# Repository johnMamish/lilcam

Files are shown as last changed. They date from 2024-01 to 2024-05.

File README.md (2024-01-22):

This is a USB camera which uses the ultra-low-power Himax HM01B0 and HM0360 sensors. It's intended to act as an evaluation platform for these sensors; commercially available evaluation platforms don't allow for the use of custom optics.

Please contact me if you're interested in buying one, we might be able to set something up.

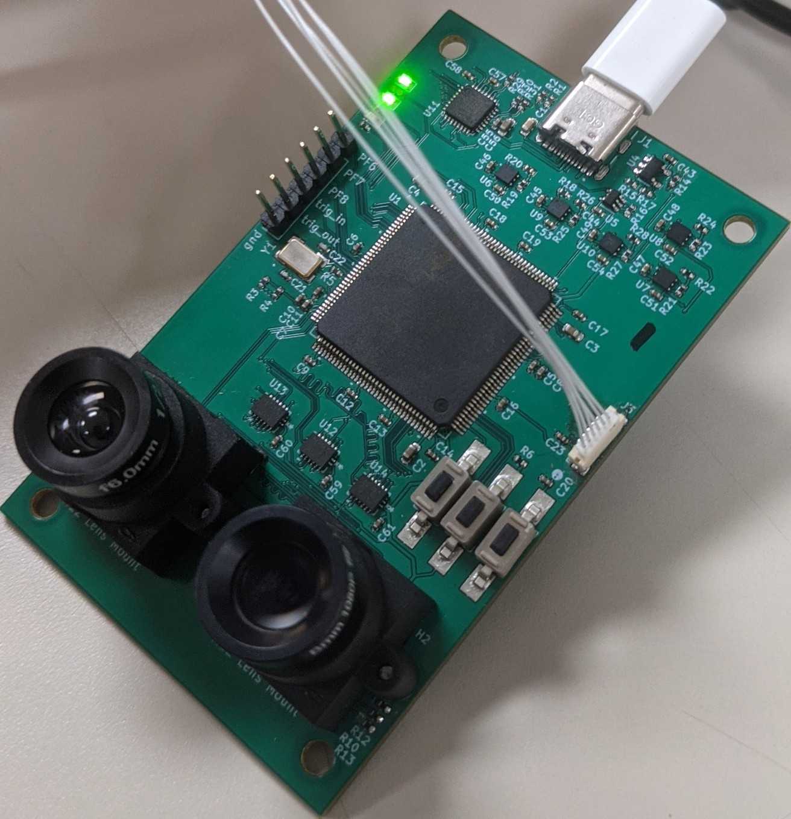
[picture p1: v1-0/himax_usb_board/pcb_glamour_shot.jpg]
photo of PCB


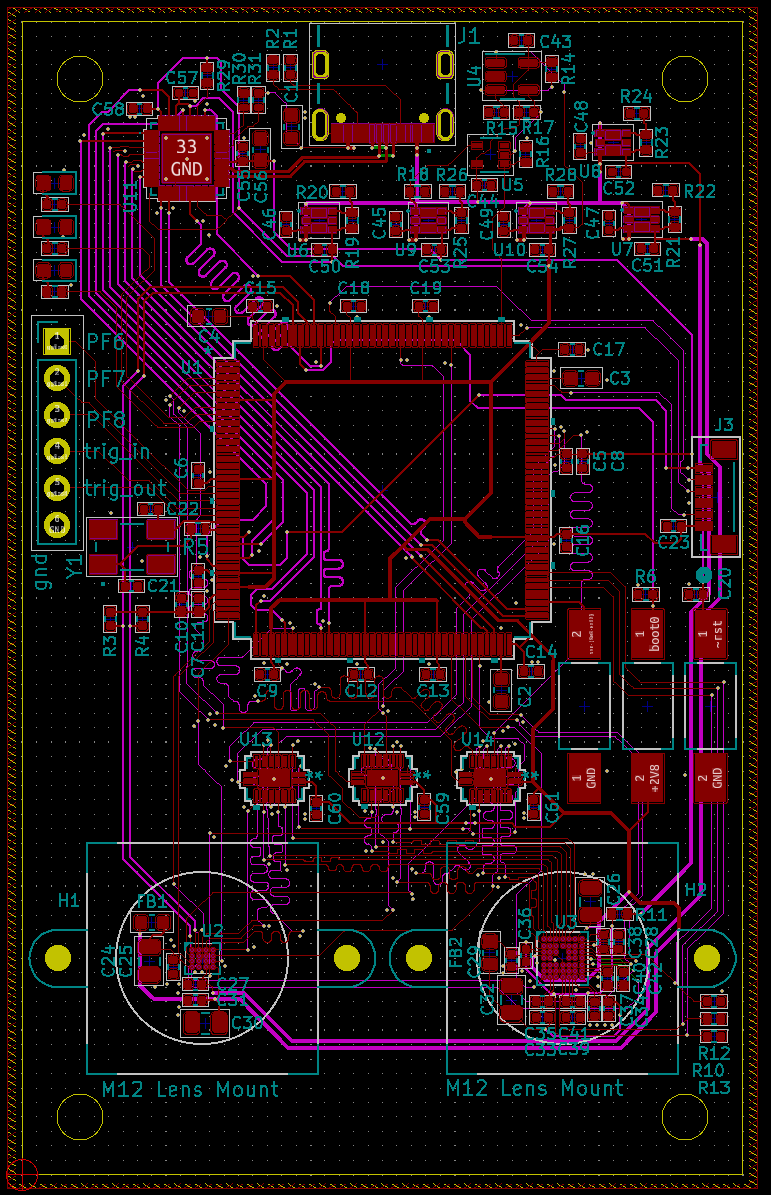
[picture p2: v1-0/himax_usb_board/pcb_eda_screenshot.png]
screenshot of EDA design


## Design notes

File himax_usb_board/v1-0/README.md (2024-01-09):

Power rails needed:
 - 3v3
    - STM32 VDDUSB   Note - must be sequenced properly.
                     Enough to have an 'enable' pin from the microcontroller plus an
 - 2v8
    - STM32 VDD      Note that I can expect it to consume ~100mA
    - HM01B0 IOVDD
    - HM01B0 AVDD
    - HM0360 IOVDD
    - HM0360 AVDD
 - 1v5
    - HM01B0 DVDD
 - 1v2
    - HM0360 DVDD

#### Schematic checklist
 - [x] STM32
     - [x] inter-module sync signal
     - [x] a few gpio for controlling external stuff
     - [x] programming connector
     - [x] a couple LEDs and buttons
     - [x] BOOT0 / reset button
 - [x] USB
     - [x] tvs diodes  (USB3300 has integrated TVS diodes)
     - [x] ULPI transciever
           USB3320
         - [x] refclk
               going to wait to start layout to decide which pin will work the best for this.
               STM32 can't generate clock on ULPI bus.
         - [x] gpio vol] i2c selection pins
 - [x] image sensor bus switch
     - [x] muxes
     - [x] camera select signal
 - [x] hm0360
     - [x] i2c selection pins
     - [x] mclk; should we provide an external clock?
           yes.
     - [x] xsleep, xshutdown, etc
     - [x] strobe
     - [x] int
 - [x] hm01b0
     - [x] mclk; should we provide an external clock?
     - [x] strobe
     - [x] int
 - [x] i2c pullups
 - [x] Crystal capacitor selection
 - [ ] check ground vias

#### PCB checklist
 - [x] lens mounting holes
 - [ ] add current sensing?

Bringup todos
 - [ ] Verify power down sequencing

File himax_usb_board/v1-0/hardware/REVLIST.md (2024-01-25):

#### Electrical
 - [ ] voltage divider going into op-amp for power supply sequencing has incorrect
       value on top. Should be < ~7.5kOhm
 - [ ] ULPI transciever might benefit from a reset line connected to MCU. This
 - [ ] Silkscreen around buttons
 - [ ] No boot0 button, but extra user button (?)
 - [ ] Mounting holes for lens mount too small
 - [ ] Two of the broken out pins should be a DFU-capable
 - [-] Sometimes camera doesnt start on initial power-on, but needs a reset cycle. Why?
       This was because the hm01b0 pixclk being configured as gated. The STM32 has an undocumented requirement that the DCMI pixclk be continuous
 - [ ] Change clock refsel bits on PHY
 - [ ] Add some sort of 'board id' resistors so that firmware can tell which board its on

#### Electrical tentative
 - [ ] Also break out FS usb port?
 - [ ] Add current monitoring for camera power rails
 - [ ] Swap MCU to chip with more flash?
 - [ ] External RAM (buffer images, fun)
 - [ ] External Flash (?)

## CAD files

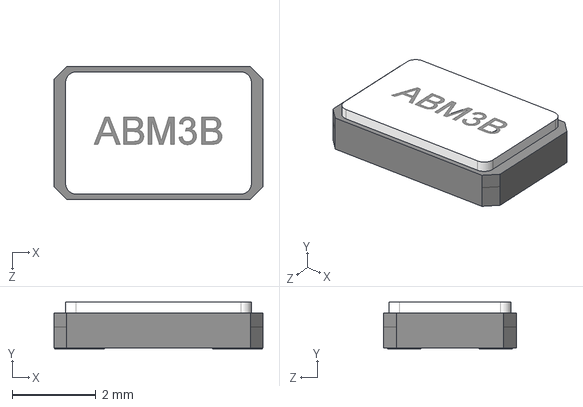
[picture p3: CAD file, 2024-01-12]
himax_usb_board/v1-0/hardware/ABM3B_12_000MHZ_B2_T/ABM3B-12.000MHZ-B2-T.step
5.00 x 1.11 x 3.18 mm

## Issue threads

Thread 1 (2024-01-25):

Change to tinyusb library + isochronous usb

johnMamish, 2024-01-25:
Currently using STM32CubeMX driver. It handles high bandwidth stuff poorly. We can do 320x240 up to ~30fps, but that's not remotely sufficient.

Should switch to a combo of tinyusb + my own code. Furthermore, we ought to change to an isochronous endpoint so we can do video properly.

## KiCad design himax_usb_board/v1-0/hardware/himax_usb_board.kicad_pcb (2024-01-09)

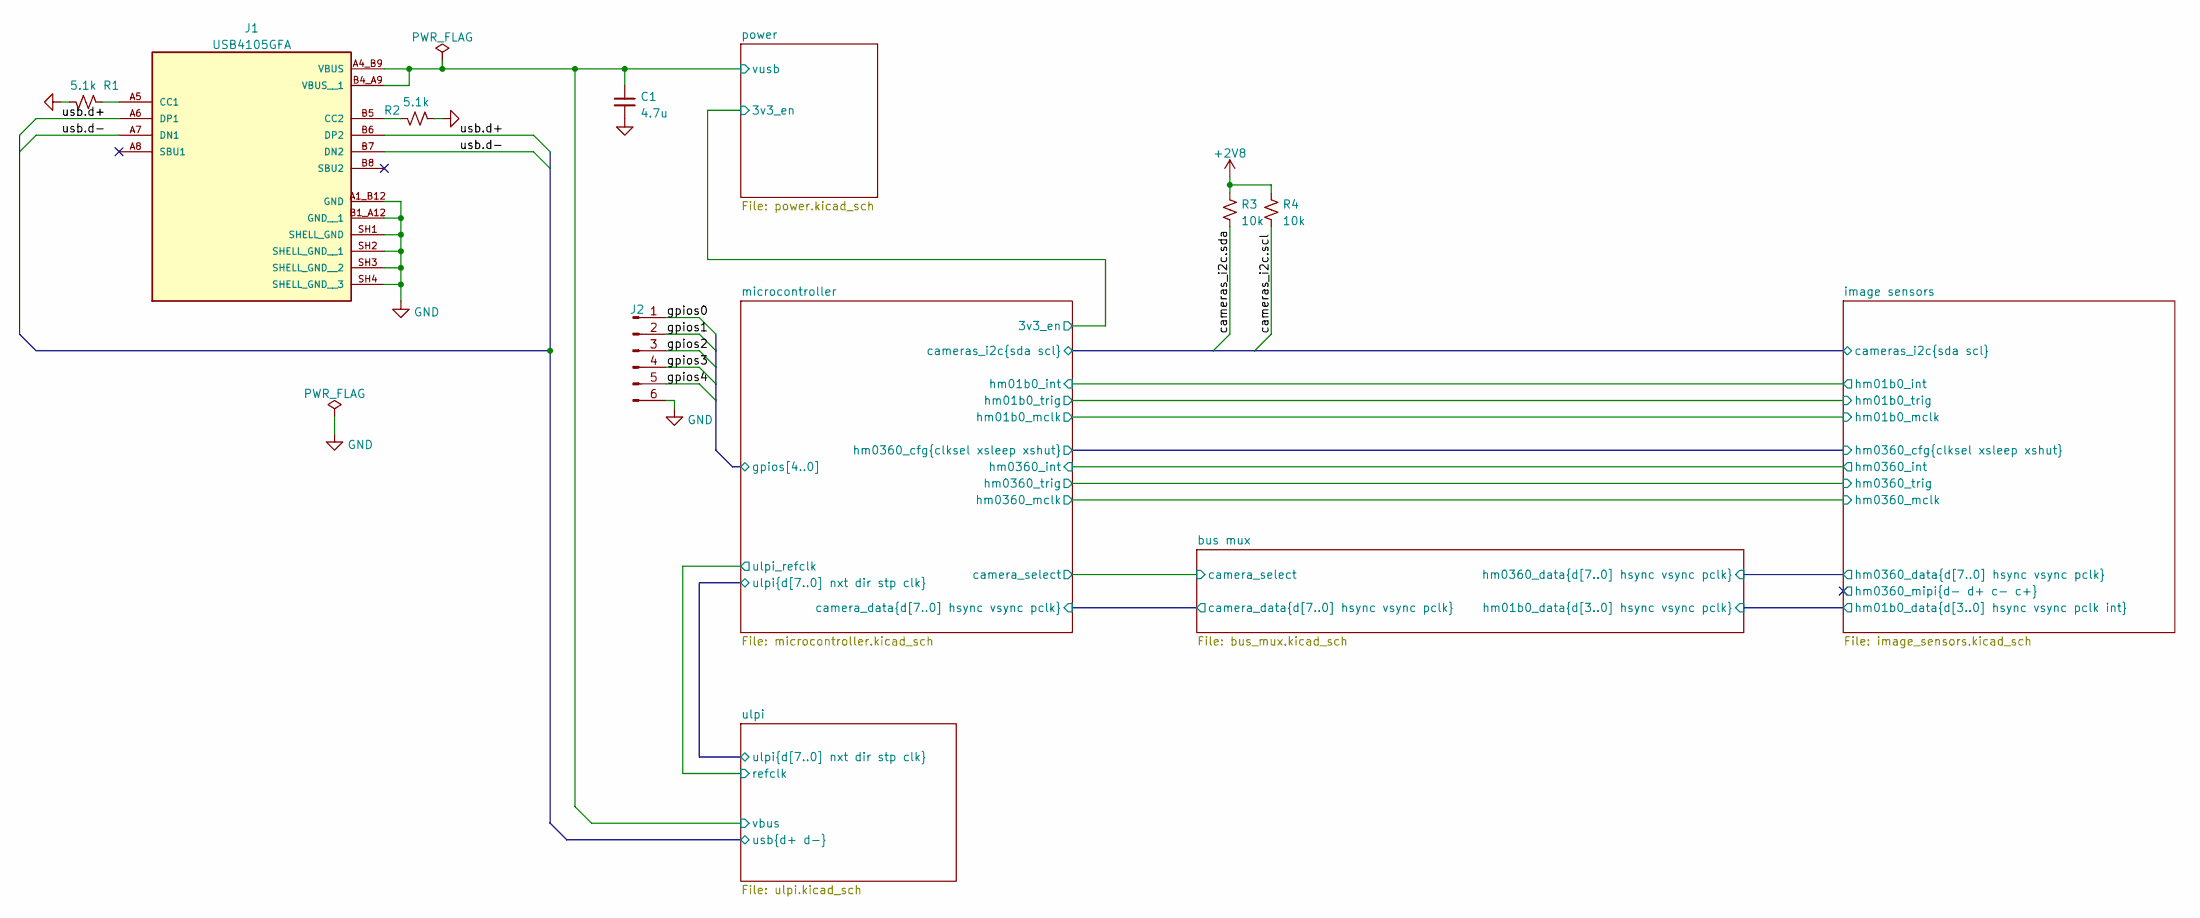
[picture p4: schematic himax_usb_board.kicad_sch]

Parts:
C1: 4.7u; C_0603_1608Metric; MFR_PN CL10A475KP8NNNC
J1: USB4105GFA; GCT_USB4105GFA; PARTREV B3
J2: Conn_01x06_Male; PinHeader_1x06_P2.54mm_Vertical; MFR_PN N/A
R1, R2: 5.1k; R_0402_1005Metric; MFR_PN ERJ-2RKF5101X
R3, R4: 10k; R_0402_1005Metric; MFR_PN ERJ-2RKF1002X

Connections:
+2V8: R3.1, R4.1; also elsewhere on the board
/image sensors/cameras_i2c.scl: R4.2; also elsewhere on the board
/image sensors/cameras_i2c.sda: R3.2; also elsewhere on the board
/microcontroller/gpios0: J2.1; also elsewhere on the board
/microcontroller/gpios1: J2.2; also elsewhere on the board
/microcontroller/gpios2: J2.3; also elsewhere on the board
/microcontroller/gpios3: J2.4; also elsewhere on the board
/microcontroller/gpios4: J2.5; also elsewhere on the board
/ulpi/usb.d+: J1.A6 (DP1), J1.B6 (DP2); also elsewhere on the board
/ulpi/usb.d-: J1.A7 (DN1), J1.B7 (DN2); also elsewhere on the board
GND: C1.2, J1.A1_B12 (GND), J1.B1_A12 (GND__1), J1.SH1 (SHELL_GND), J1.SH2 (SHELL_GND__1), J1.SH3 (SHELL_GND__2), J1.SH4 (SHELL_GND__3), J2.6, R1.1, R2.1; also elsewhere on the board
unnamed: J1.A5 (CC1), R1.2
unnamed: J1.B5 (CC2), R2.2
VCC: C1.1, J1.A4_B9 (VBUS), J1.B4_A9 (VBUS__1); also elsewhere on the board

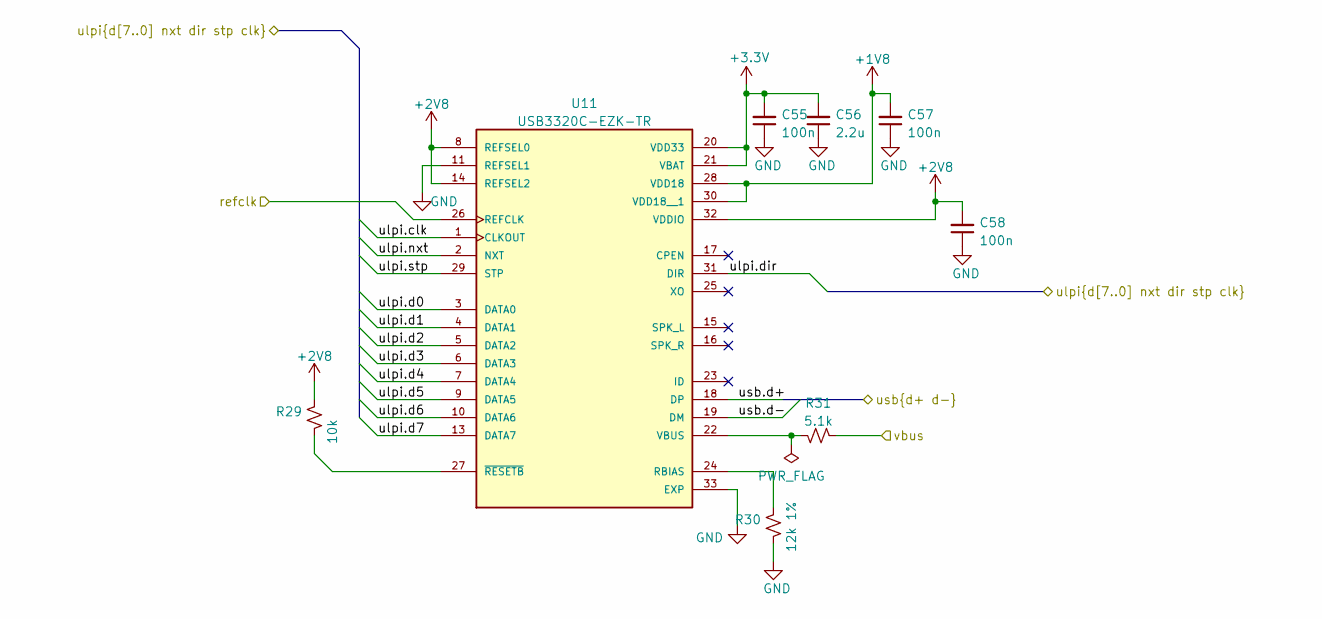
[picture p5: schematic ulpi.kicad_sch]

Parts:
C55, C57, C58: 100n; C_0402_1005Metric; MFR_PN CL05B104KP5NNNC
C56: 2.2u; C_0603_1608Metric; MFR_PN CL10A225KP8NNNC
R29: 10k; R_0402_1005Metric; MFR_PN ERJ-2RKF1002X
R30: 12k 1%; R_0402_1005Metric; MFR_PN ERJ-2RKF1202X
R31: 5.1k; R_0402_1005Metric; MFR_PN ERJ-2RKF5101X
U11: USB3320C-EZK-TR; QFN50P500X500X100-33N330X330; MFR_PN USB3320C-EZK-TR

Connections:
+1V8: C57.2, U11.28 (VDD18), U11.30 (VDD18__1); also elsewhere on the board
+2V8: C58.2, R29.1, U11.8 (REFSEL0), U11.14 (REFSEL2), U11.32 (VDDIO); also elsewhere on the board
/microcontroller/ulpi.clk: U11.1 (CLKOUT); also elsewhere on the board
/microcontroller/ulpi.d0: U11.3 (DATA0); also elsewhere on the board
/microcontroller/ulpi.d1: U11.4 (DATA1); also elsewhere on the board
/microcontroller/ulpi.d2: U11.5 (DATA2); also elsewhere on the board
/microcontroller/ulpi.d3: U11.6 (DATA3); also elsewhere on the board
/microcontroller/ulpi.d4: U11.7 (DATA4); also elsewhere on the board
/microcontroller/ulpi.d5: U11.9 (DATA5); also elsewhere on the board
/microcontroller/ulpi.d6: U11.10 (DATA6); also elsewhere on the board
/microcontroller/ulpi.d7: U11.13 (DATA7); also elsewhere on the board
/microcontroller/ulpi.dir: U11.31 (DIR); also elsewhere on the board
/microcontroller/ulpi.nxt: U11.2 (NXT); also elsewhere on the board
/microcontroller/ulpi.stp: U11.29 (STP); also elsewhere on the board
/microcontroller/ulpi_refclk: U11.26 (REFCLK); also elsewhere on the board
/ulpi/usb.d+: U11.18 (DP); also elsewhere on the board
/ulpi/usb.d-: U11.19 (DM); also elsewhere on the board
GND: C55.1, C56.1, C57.1, C58.1, R30.2, U11.11 (REFSEL1), U11.33 (EXP); also elsewhere on the board
unnamed: R29.2, U11.27 (~RESETB)
unnamed: R30.1, U11.24 (RBIAS)
unnamed: R31.1, U11.22 (VBUS)
VCC: R31.2; also elsewhere on the board

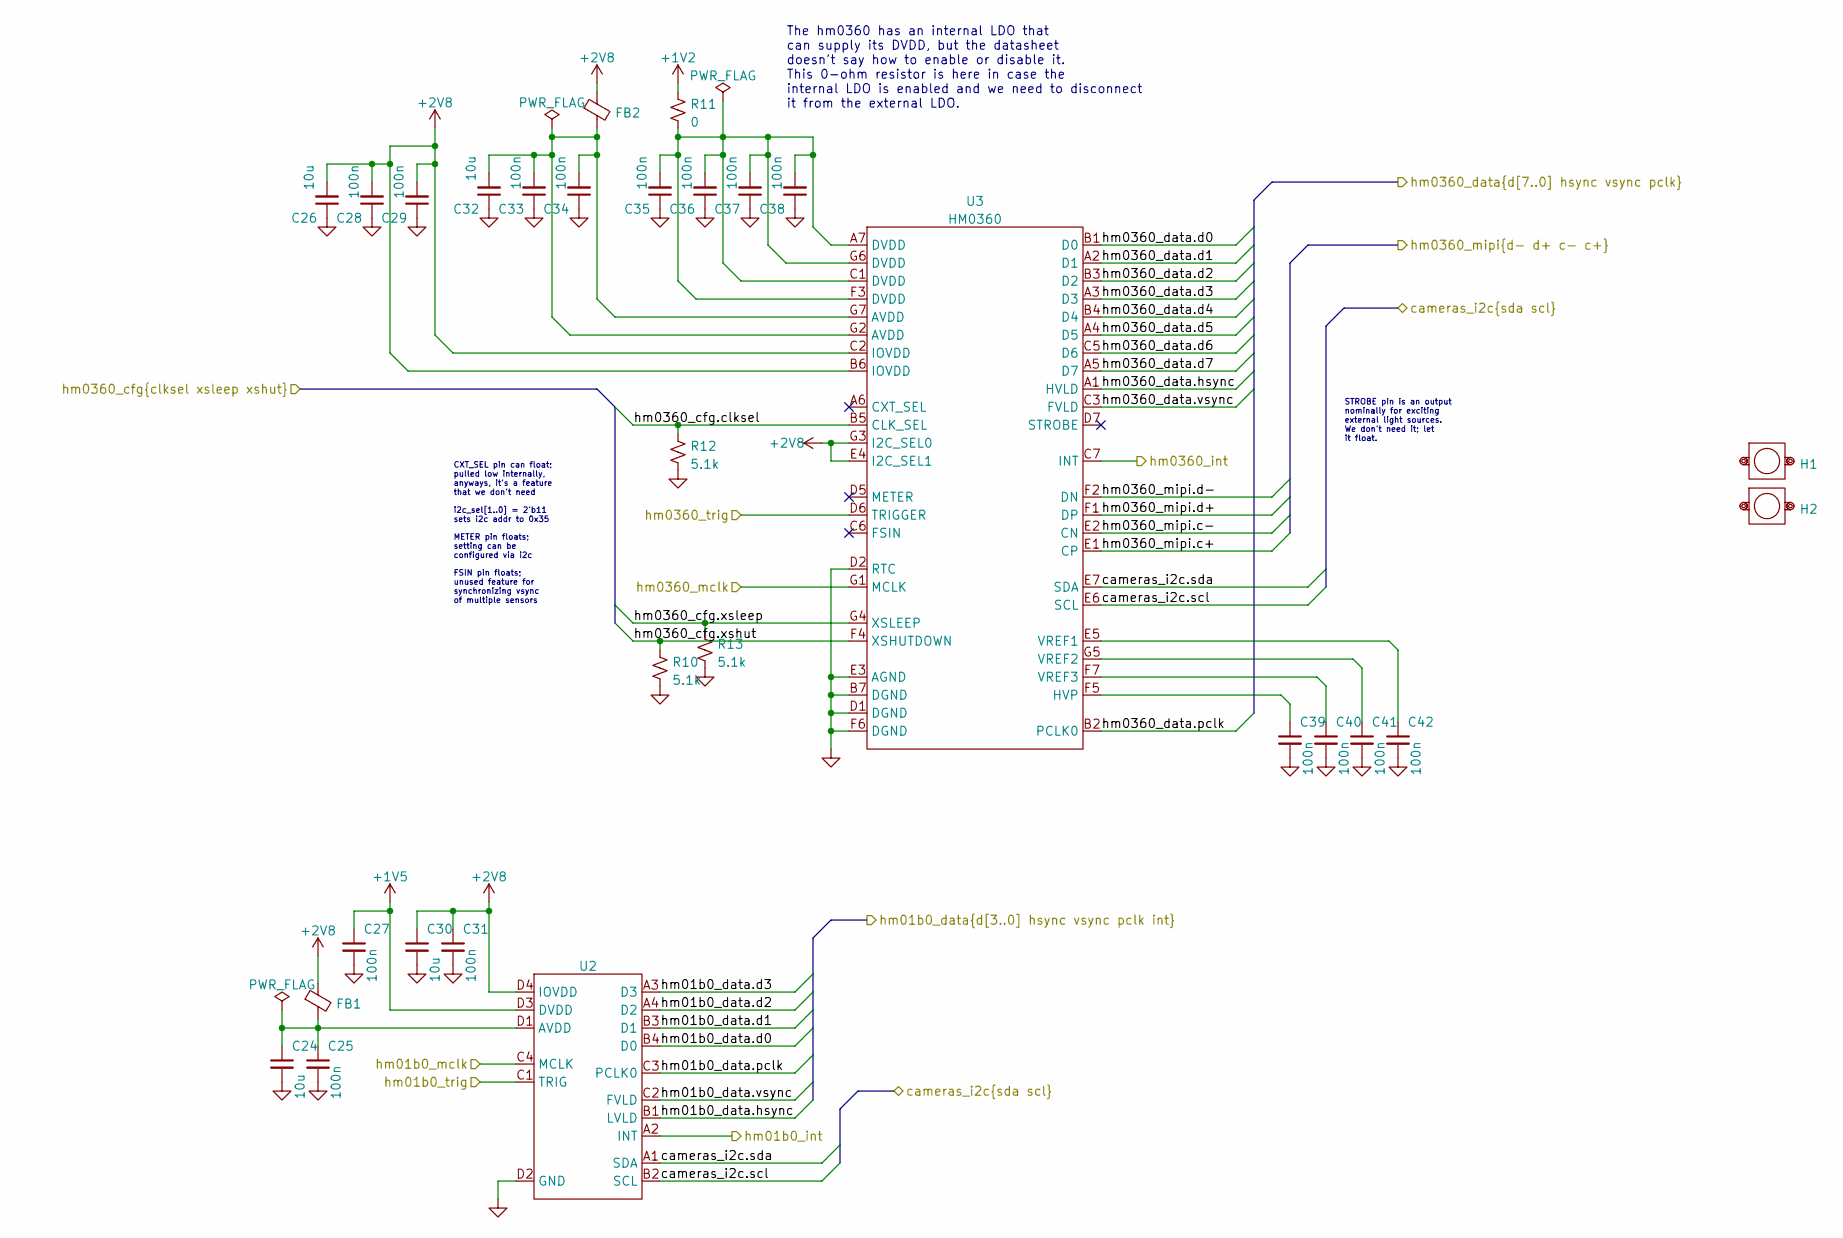
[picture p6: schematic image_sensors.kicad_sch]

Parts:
C24, C26, C30, C32: 10u; C_0805_2012Metric; MFR_PN CL21A106KOQNNNE
C25, C27, C28, C29, C31, C33, C34, C35, C36, C37, C38, C39, C40, C41, C42: 100n; C_0402_1005Metric; MFR_PN CL05B104KP5NNNC
FB1, FB2: FerriteBead_Small; C_0603_1608Metric; MFR_PN MPZ1608B471ATA00
H1, H2: m12_lens_mount_mech; MFR_PN N/A
R10, R12, R13: 5.1k; R_0402_1005Metric; MFR_PN ERJ-2RKF5101X
R11: 0; R_0402_1005Metric; MFR_PN ERJ-2GE0R00X
U2: hm01b0-mwa; hm01b0-xWA; MFR_PN hm01b0-mwa
U3: HM0360; hm0360; MFR_PN HM0360-MWA

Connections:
+1V2: R11.1; also elsewhere on the board
+1V5: C27.1, U2.D3 (DVDD); also elsewhere on the board
+2V8: C26.2, C28.2, C29.2, C30.1, C31.1, FB1.1, FB2.1, U2.D4 (IOVDD), U3.B6 (IOVDD), U3.C2 (IOVDD), U3.E4 (I2C_SEL1), U3.G3 (I2C_SEL0); also elsewhere on the board
/bus mux/hm01b0_data.d0: U2.B4 (D0); also elsewhere on the board
/bus mux/hm01b0_data.d1: U2.B3 (D1); also elsewhere on the board
/bus mux/hm01b0_data.d2: U2.A4 (D2); also elsewhere on the board
/bus mux/hm01b0_data.d3: U2.A3 (D3); also elsewhere on the board
/bus mux/hm01b0_data.hsync: U2.B1 (LVLD); also elsewhere on the board
/bus mux/hm01b0_data.pclk: U2.C3 (PCLK0); also elsewhere on the board
/bus mux/hm01b0_data.vsync: U2.C2 (FVLD); also elsewhere on the board
/bus mux/hm0360_data.d0: U3.B1 (D0); also elsewhere on the board
/bus mux/hm0360_data.d1: U3.A2 (D1); also elsewhere on the board
/bus mux/hm0360_data.d2: U3.B3 (D2); also elsewhere on the board
/bus mux/hm0360_data.d3: U3.A3 (D3); also elsewhere on the board
/bus mux/hm0360_data.d4: U3.B4 (D4); also elsewhere on the board
/bus mux/hm0360_data.d5: U3.A4 (D5); also elsewhere on the board
/bus mux/hm0360_data.d6: U3.C5 (D6); also elsewhere on the board
/bus mux/hm0360_data.d7: U3.A5 (D7); also elsewhere on the board
/bus mux/hm0360_data.hsync: U3.A1 (HVLD); also elsewhere on the board
/bus mux/hm0360_data.pclk: U3.B2 (PCLK0); also elsewhere on the board
/bus mux/hm0360_data.vsync: U3.C3 (FVLD); also elsewhere on the board
/image sensors/cameras_i2c.scl: U2.B2 (SCL), U3.E6 (SCL); also elsewhere on the board
/image sensors/cameras_i2c.sda: U2.A1 (SDA), U3.E7 (SDA); also elsewhere on the board
/image sensors/hm01b0_int: U2.A2 (INT); also elsewhere on the board
/image sensors/hm01b0_mclk: U2.C4 (MCLK); also elsewhere on the board
/image sensors/hm01b0_trig: U2.C1 (TRIG); also elsewhere on the board
/image sensors/hm0360_cfg.clksel: R12.1, U3.B5 (CLK_SEL); also elsewhere on the board
/image sensors/hm0360_cfg.xshut: R10.1, U3.F4 (XSHUTDOWN); also elsewhere on the board
/image sensors/hm0360_cfg.xsleep: R13.1, U3.G4 (XSLEEP); also elsewhere on the board
/image sensors/hm0360_int: U3.C7 (INT); also elsewhere on the board
/image sensors/hm0360_mclk: U3.G1 (MCLK); also elsewhere on the board
/image sensors/hm0360_mipi.c+: U3.E1 (CP)
/image sensors/hm0360_mipi.c-: U3.E2 (CN)
/image sensors/hm0360_mipi.d+: U3.F1 (DP)
/image sensors/hm0360_mipi.d-: U3.F2 (DN)
/image sensors/hm0360_trig: U3.D6 (TRIGGER); also elsewhere on the board
GND: C24.2, C25.2, C26.1, C27.2, C28.1, C29.1, C30.2, C31.2, C32.1, C33.1, C34.1, C35.1, C36.1, C37.1, C38.1, C39.2, C40.2, C41.2, C42.2, R10.2, R12.2, R13.2, U2.D2 (GND), U3.B7 (DGND), U3.D1 (DGND), U3.D2 (RTC), U3.E3 (AGND), U3.F6 (DGND); also elsewhere on the board
unnamed: C24.1, C25.1, FB1.2, U2.D1 (AVDD)
unnamed: C32.2, C33.2, C34.2, FB2.2, U3.G2 (AVDD), U3.G7 (AVDD)
unnamed: C35.2, C36.2, C37.2, C38.2, R11.2, U3.A7 (DVDD), U3.C1 (DVDD), U3.F3 (DVDD), U3.G6 (DVDD)
unnamed: C39.1, U3.F5 (HVP)
unnamed: C40.1, U3.F7 (VREF3)
unnamed: C41.1, U3.G5 (VREF2)
unnamed: C42.1, U3.E5 (VREF1)

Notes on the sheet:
CXT_SEL pin can float; pulled low internally, anyways, it's a feature that we don't need
STROBE pin is an output nominally for exciting external light sources. We don't need it; let it float.
METER pin floats; setting can be configured via i2c
The hm0360 has an internal LDO that can supply its DVDD, but the datasheet doesn't say how to enable or disable it. This 0-ohm resistor is here in case the internal LDO is enabled and we need to disconnect it from the external LDO.
FSIN pin floats; unused feature for synchronizing vsync of multiple sensors
i2c_sel[1..0] = 2'b11 sets i2c addr to 0x35

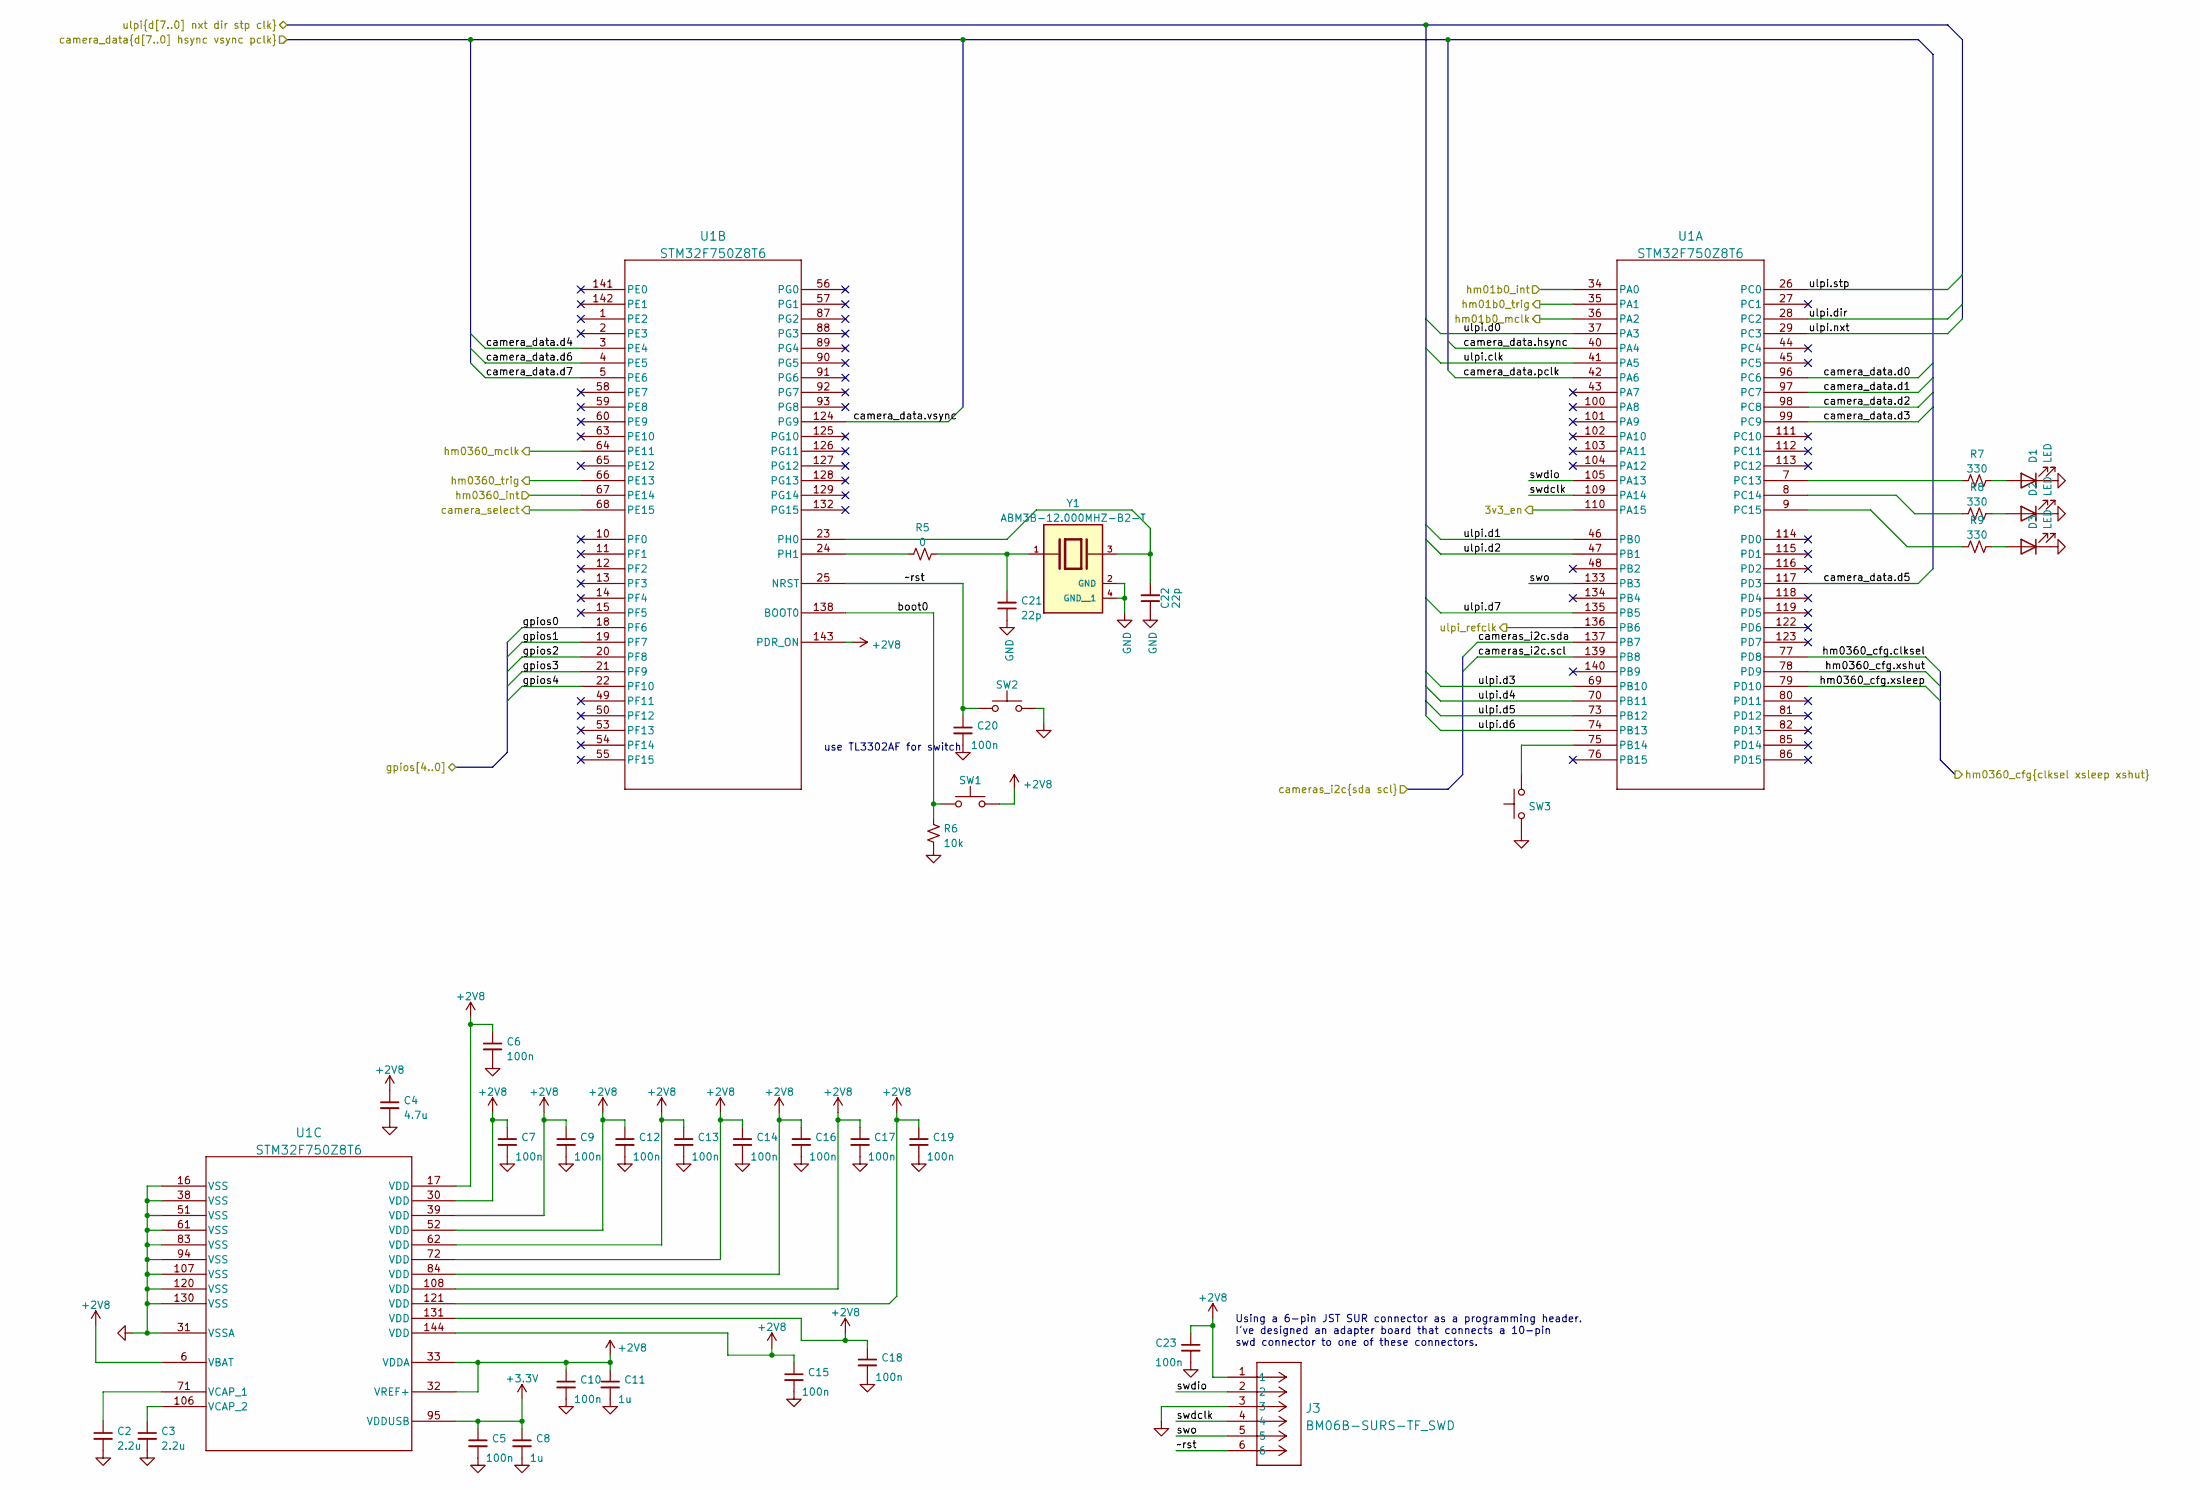
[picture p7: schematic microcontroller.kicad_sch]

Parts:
C2, C3: 2.2u; C_0603_1608Metric; MFR_PN CL10A225KP8NNNC
C4: 4.7u; C_0603_1608Metric; MFR_PN CL10A475KP8NNNC
C5, C6, C7, C9, C10, C12, C13, C14, C15, C16, C17, C18, C19, C20, C23: 100n; C_0402_1005Metric; MFR_PN CL05B104KP5NNNC
C8, C11: 1u; C_0402_1005Metric; MFR_PN CL05A105KO5NNNC
C21, C22: 22p; C_0402_1005Metric; MFR_PN CL05C220JB51PNC
D1, D2, D3: LED; LED_0603_1608Metric; MFR_PN LTST-C191KGKT
J3: BM06B-SURS-TF_SWD; CONN6x1_BM06B-SURS-TF_JST; MFR_PN BM06B-SURS-TF
R5: 0; R_0402_1005Metric; MFR_PN ERJ-2GE0R00X
R6: 10k; R_0402_1005Metric; MFR_PN ERJ-2RKF1002X
R7, R8, R9: 330; R_0402_1005Metric; MFR_PN ERJ-2RKF3300X
SW1, SW2, SW3: SW_Push; TL3302AFxxxQG; MFR_PN TL3302AF180QG
U1: STM32F750Z8T6; LQFP-144_STM; MFR_PN STM32F750Z8T6
Y1: ABM3B-12.000MHZ-B2-T; XTAL_ABM3B-12.000MHZ-B2-T; PARTREV 08.25.15

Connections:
+2V8: C4.1, C6.1, C7.1, C9.1, C10.1, C11.1, C12.1, C13.1, C14.1, C15.1, C16.1, C17.1, C18.1, C19.1, C23.1, J3.1, SW1.2, U1.6 (VBAT), U1.17 (VDD), U1.30 (VDD), U1.32 (VREF+), U1.33 (VDDA), U1.39 (VDD), U1.52 (VDD), U1.62 (VDD), U1.72 (VDD), U1.84 (VDD), U1.108 (VDD), U1.121 (VDD), U1.131 (VDD), U1.143 (PDR_ON), U1.144 (VDD); also elsewhere on the board
/bus mux/camera_data.d0: U1.96 (PC6); also elsewhere on the board
/bus mux/camera_data.d1: U1.97 (PC7); also elsewhere on the board
/bus mux/camera_data.d2: U1.98 (PC8); also elsewhere on the board
/bus mux/camera_data.d3: U1.99 (PC9); also elsewhere on the board
/bus mux/camera_data.d4: U1.3 (PE4); also elsewhere on the board
/bus mux/camera_data.d5: U1.117 (PD3); also elsewhere on the board
/bus mux/camera_data.d6: U1.4 (PE5); also elsewhere on the board
/bus mux/camera_data.d7: U1.5 (PE6); also elsewhere on the board
/bus mux/camera_data.hsync: U1.40 (PA4); also elsewhere on the board
/bus mux/camera_data.pclk: U1.42 (PA6); also elsewhere on the board
/bus mux/camera_data.vsync: U1.124 (PG9); also elsewhere on the board
/bus mux/camera_select: U1.68 (PE15); also elsewhere on the board
/image sensors/cameras_i2c.scl: U1.139 (PB8); also elsewhere on the board
/image sensors/cameras_i2c.sda: U1.137 (PB7); also elsewhere on the board
/image sensors/hm01b0_int: U1.34 (PA0); also elsewhere on the board
/image sensors/hm01b0_mclk: U1.36 (PA2); also elsewhere on the board
/image sensors/hm01b0_trig: U1.35 (PA1); also elsewhere on the board
/image sensors/hm0360_cfg.clksel: U1.77 (PD8); also elsewhere on the board
/image sensors/hm0360_cfg.xshut: U1.78 (PD9); also elsewhere on the board
/image sensors/hm0360_cfg.xsleep: U1.79 (PD10); also elsewhere on the board
/image sensors/hm0360_int: U1.67 (PE14); also elsewhere on the board
/image sensors/hm0360_mclk: U1.64 (PE11); also elsewhere on the board
/image sensors/hm0360_trig: U1.66 (PE13); also elsewhere on the board
/microcontroller/3v3_en: U1.110 (PA15); also elsewhere on the board
/microcontroller/boot0: R6.1, SW1.1, U1.138 (BOOT0)
/microcontroller/gpios0: U1.18 (PF6); also elsewhere on the board
/microcontroller/gpios1: U1.19 (PF7); also elsewhere on the board
/microcontroller/gpios2: U1.20 (PF8); also elsewhere on the board
/microcontroller/gpios3: U1.21 (PF9); also elsewhere on the board
/microcontroller/gpios4: U1.22 (PF10); also elsewhere on the board
/microcontroller/swdclk: J3.4, U1.109 (PA14)
/microcontroller/swdio: J3.2, U1.105 (PA13)
/microcontroller/swo: J3.5, U1.133 (PB3)
/microcontroller/ulpi.clk: U1.41 (PA5); also elsewhere on the board
/microcontroller/ulpi.d0: U1.37 (PA3); also elsewhere on the board
/microcontroller/ulpi.d1: U1.46 (PB0); also elsewhere on the board
/microcontroller/ulpi.d2: U1.47 (PB1); also elsewhere on the board
/microcontroller/ulpi.d3: U1.69 (PB10); also elsewhere on the board
/microcontroller/ulpi.d4: U1.70 (PB11); also elsewhere on the board
/microcontroller/ulpi.d5: U1.73 (PB12); also elsewhere on the board
/microcontroller/ulpi.d6: U1.74 (PB13); also elsewhere on the board
/microcontroller/ulpi.d7: U1.135 (PB5); also elsewhere on the board
/microcontroller/ulpi.dir: U1.28 (PC2); also elsewhere on the board
/microcontroller/ulpi.nxt: U1.29 (PC3); also elsewhere on the board
/microcontroller/ulpi.stp: U1.26 (PC0); also elsewhere on the board
/microcontroller/ulpi_refclk: U1.136 (PB6); also elsewhere on the board
/microcontroller/~rst: C20.1, J3.6, SW2.1, U1.25 (NRST)
GND: C2.2, C3.2, C4.2, C5.2, C6.2, C7.2, C8.2, C9.2, C10.2, C11.2, C12.2, C13.2, C14.2, C15.2, C16.2, C17.2, C18.2, C19.2, C20.2, C21.1, C22.1, C23.2, D1.1 (K), D2.1 (K), D3.1 (K), J3.3, R6.2, SW2.2, SW3.1, U1.16 (VSS), U1.31 (VSSA), U1.38 (VSS), U1.51 (VSS), U1.61 (VSS), U1.83 (VSS), U1.94 (VSS), U1.107 (VSS), U1.120 (VSS), U1.130 (VSS), Y1.2 (GND), Y1.4 (GND__1); also elsewhere on the board
unnamed: C2.1, U1.71 (VCAP_1)
unnamed: C3.1, U1.106 (VCAP_2)
unnamed: C21.2, R5.2, Y1.1
unnamed: C22.2, U1.23 (PH0), Y1.3
unnamed: D1.2 (A), R7.2
unnamed: D2.2 (A), R8.2
unnamed: D3.2 (A), R9.2
unnamed: R5.1, U1.24 (PH1)
unnamed: R7.1, U1.7 (PC13)
unnamed: R8.1, U1.8 (PC14)
unnamed: R9.1, U1.9 (PC15)
unnamed: SW3.2, U1.75 (PB14)

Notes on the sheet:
Using a 6-pin JST SUR connector as a programming header. I've designed an adapter board that connects a 10-pin swd connector to one of these connectors.
use TL3302AF for switch

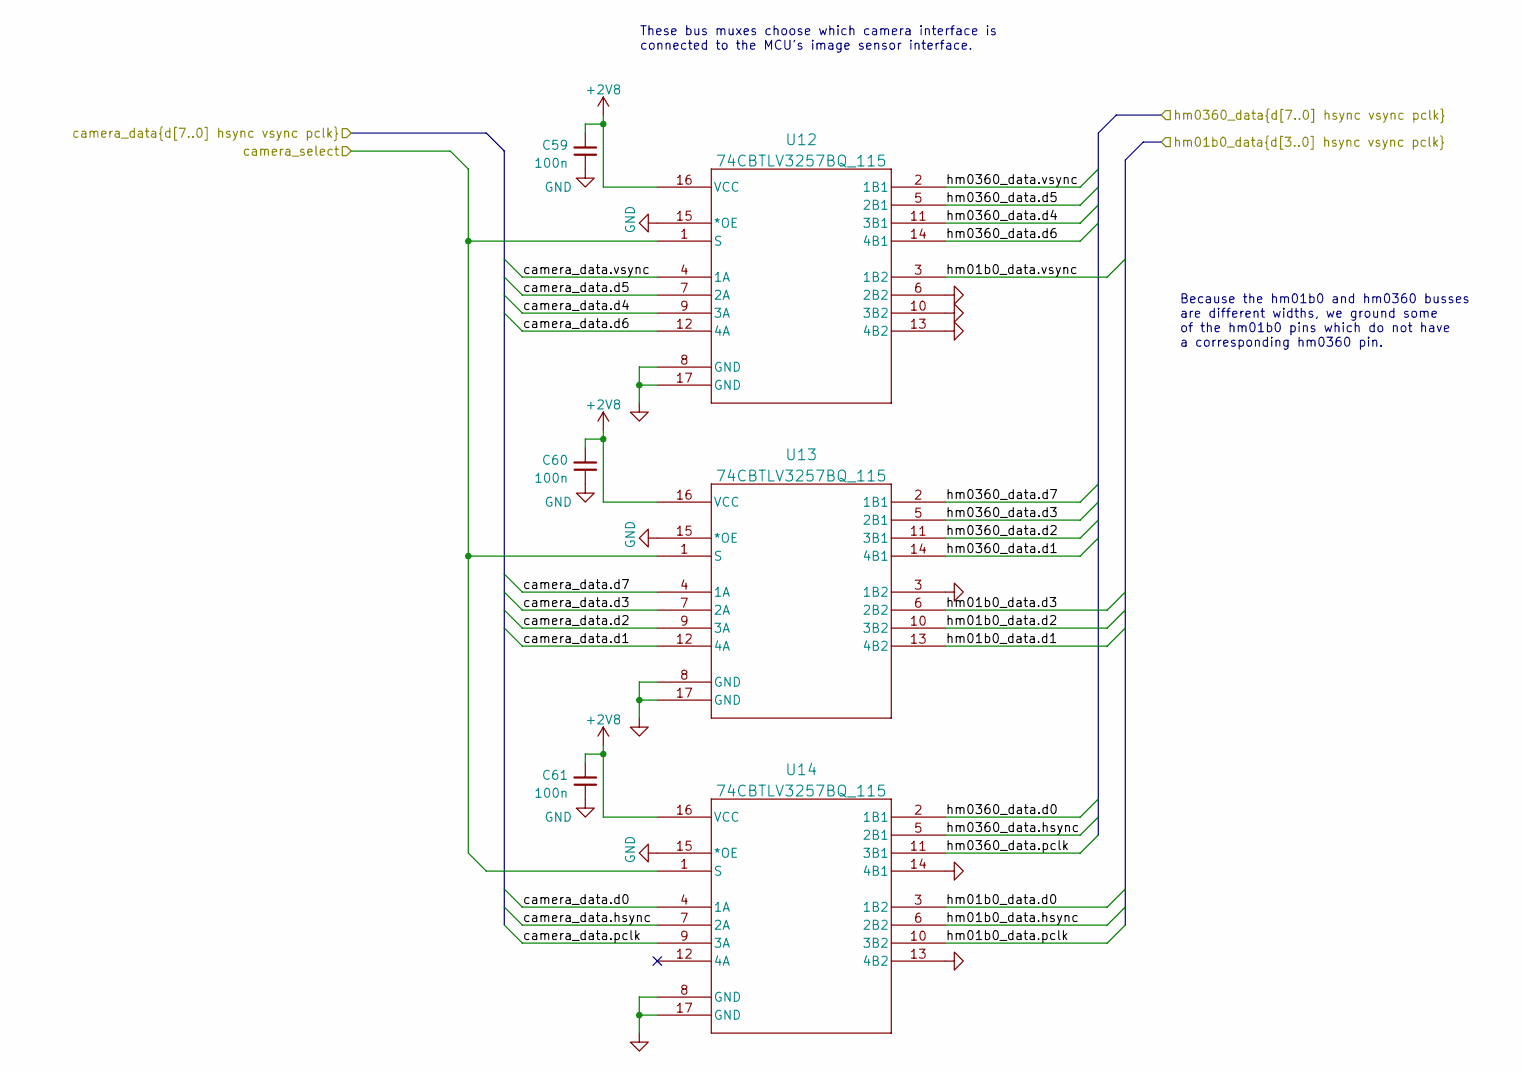
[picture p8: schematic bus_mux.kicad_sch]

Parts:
C59, C60, C61: 100n; C_0402_1005Metric; MFR_PN CL05B104KP5NNNC
U12, U13, U14: 74CBTLV3257BQ_115; DHVQFN16_SOT763-1_NEX; MFR_PN 74CBTLV3257BQ,115

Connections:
+2V8: C59.2, C60.2, C61.2, U12.16 (VCC), U13.16 (VCC), U14.16 (VCC); also elsewhere on the board
/bus mux/camera_data.d0: U14.4 (1A); also elsewhere on the board
/bus mux/camera_data.d1: U13.12 (4A); also elsewhere on the board
/bus mux/camera_data.d2: U13.9 (3A); also elsewhere on the board
/bus mux/camera_data.d3: U13.7 (2A); also elsewhere on the board
/bus mux/camera_data.d4: U12.9 (3A); also elsewhere on the board
/bus mux/camera_data.d5: U12.7 (2A); also elsewhere on the board
/bus mux/camera_data.d6: U12.12 (4A); also elsewhere on the board
/bus mux/camera_data.d7: U13.4 (1A); also elsewhere on the board
/bus mux/camera_data.hsync: U14.7 (2A); also elsewhere on the board
/bus mux/camera_data.pclk: U14.9 (3A); also elsewhere on the board
/bus mux/camera_data.vsync: U12.4 (1A); also elsewhere on the board
/bus mux/camera_select: U12.1 (S), U13.1 (S), U14.1 (S); also elsewhere on the board
/bus mux/hm01b0_data.d0: U14.3 (1B2); also elsewhere on the board
/bus mux/hm01b0_data.d1: U13.13 (4B2); also elsewhere on the board
/bus mux/hm01b0_data.d2: U13.10 (3B2); also elsewhere on the board
/bus mux/hm01b0_data.d3: U13.6 (2B2); also elsewhere on the board
/bus mux/hm01b0_data.hsync: U14.6 (2B2); also elsewhere on the board
/bus mux/hm01b0_data.pclk: U14.10 (3B2); also elsewhere on the board
/bus mux/hm01b0_data.vsync: U12.3 (1B2); also elsewhere on the board
/bus mux/hm0360_data.d0: U14.2 (1B1); also elsewhere on the board
/bus mux/hm0360_data.d1: U13.14 (4B1); also elsewhere on the board
/bus mux/hm0360_data.d2: U13.11 (3B1); also elsewhere on the board
/bus mux/hm0360_data.d3: U13.5 (2B1); also elsewhere on the board
/bus mux/hm0360_data.d4: U12.11 (3B1); also elsewhere on the board
/bus mux/hm0360_data.d5: U12.5 (2B1); also elsewhere on the board
/bus mux/hm0360_data.d6: U12.14 (4B1); also elsewhere on the board
/bus mux/hm0360_data.d7: U13.2 (1B1); also elsewhere on the board
/bus mux/hm0360_data.hsync: U14.5 (2B1); also elsewhere on the board
/bus mux/hm0360_data.pclk: U14.11 (3B1); also elsewhere on the board
/bus mux/hm0360_data.vsync: U12.2 (1B1); also elsewhere on the board
GND: C59.1, C60.1, C61.1, U12.6 (2B2), U12.8 (GND), U12.10 (3B2), U12.13 (4B2), U12.15 (*OE), U12.17 (GND), U13.3 (1B2), U13.8 (GND), U13.15 (*OE), U13.17 (GND), U14.8 (GND), U14.13 (4B2), U14.14 (4B1), U14.15 (*OE), U14.17 (GND); also elsewhere on the board

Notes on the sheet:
These bus muxes choose which camera interface is connected to the MCU's image sensor interface.
Because the hm01b0 and hm0360 busses are different widths, we ground some of the hm01b0 pins which do not have a corresponding hm0360 pin.

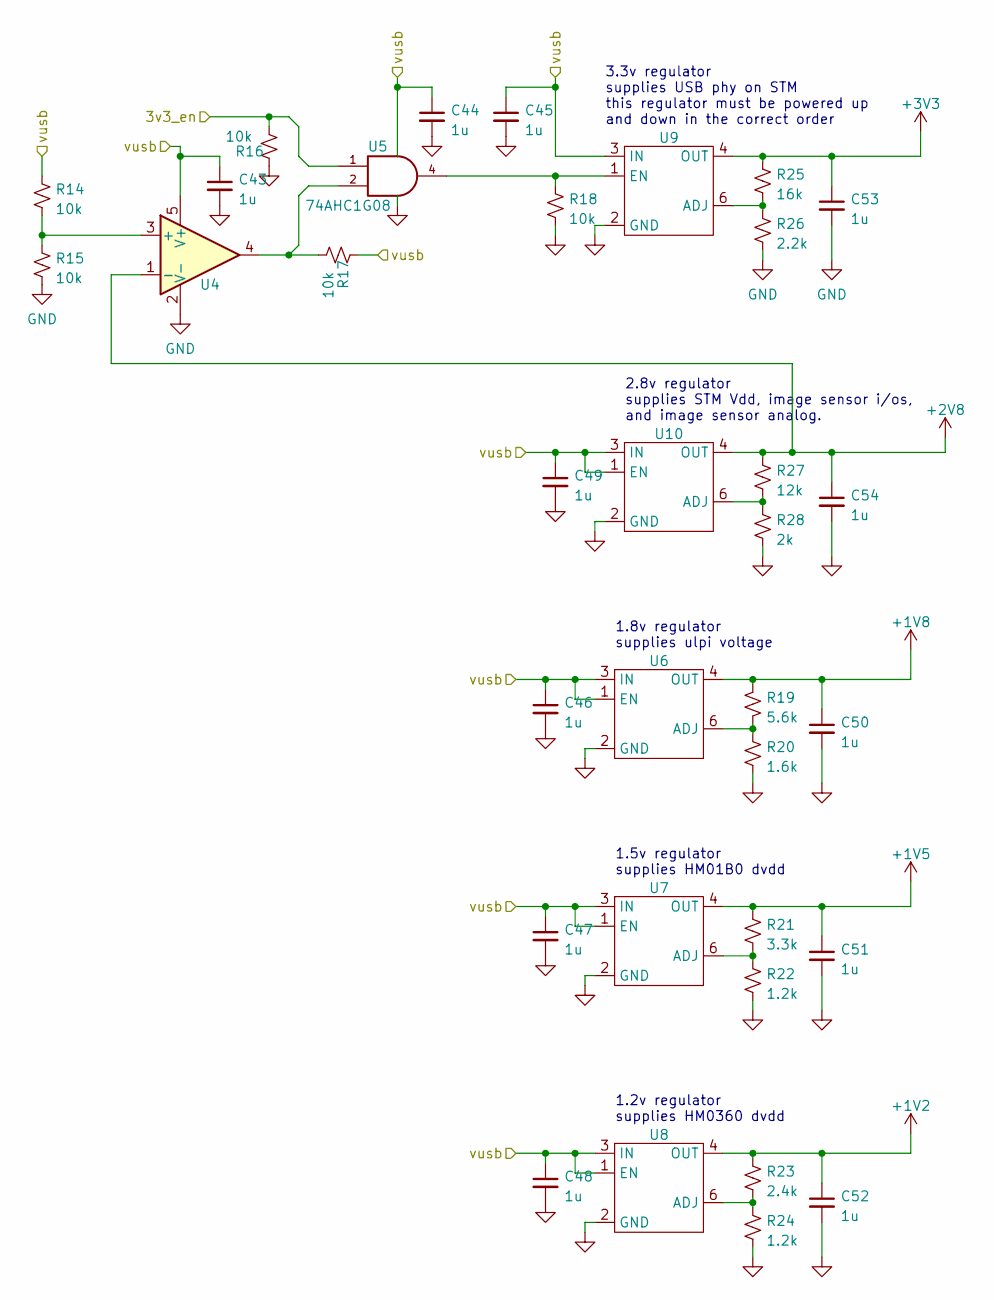
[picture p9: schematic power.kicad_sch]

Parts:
C43, C44, C45, C46, C47, C48, C49, C50, C51, C52, C53, C54: 1u; C_0402_1005Metric; MFR_PN CL05A105KO5NNNC
R14, R15, R16, R17, R18: 10k; R_0402_1005Metric; MFR_PN ERJ-2RKF1002X
R19: 5.6k; R_0402_1005Metric; MFR_PN ERJ-2RKF5601X
R20: 1.6k; R_0402_1005Metric; MFR_PN ERJ-2RKF1601X
R21: 3.3k; R_0402_1005Metric; MFR_PN ERJ-2RKF3301X
R22, R24: 1.2k; R_0402_1005Metric; MFR_PN ERJ-2RKF1201X
R23: 2.4k; R_0402_1005Metric; MFR_PN ERJ-2RKF2401X
R25: 16k; R_0402_1005Metric; MFR_PN ERJ-2RKF1602X
R26: 2.2k; R_0402_1005Metric; MFR_PN ERJ-2RKF2201X
R27: 12k; R_0402_1005Metric; MFR_PN ERJ-2RKF1202X
R28: 2k; R_0402_1005Metric; MFR_PN ERJ-2RKF2001X
U4: TL331; SOT-23-5; MFR_PN TL331IDBVR
U5: 74AHC1G08; SOT-353_SC-70-5; MFR_PN SN74AHC1G08DCKR
U6, U7, U8, U9, U10: AP7331-SNG-7; DFN200X200X60-8N; MFR_PN AP7331-SNG-7

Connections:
+1V2: C52.1, R23.1, U8.4 (OUT); also elsewhere on the board
+1V5: C51.1, R21.1, U7.4 (OUT); also elsewhere on the board
+1V8: C50.1, R19.1, U6.4 (OUT); also elsewhere on the board
+2V8: C54.1, R27.1, U4.1 (-), U10.4 (OUT); also elsewhere on the board
/microcontroller/3v3_en: R16.1, U5.1; also elsewhere on the board
GND: C43.2, C44.2, C45.2, C46.2, C47.2, C48.2, C49.2, C50.2, C51.2, C52.2, C53.2, C54.2, R15.2, R16.2, R18.2, R20.2, R22.2, R24.2, R26.2, R28.2, U4.2 (V-), U5.3 (GND), U6.2 (GND), U6.7 (GNDPAD1), U6.8 (GNDPAD2), U7.2 (GND), U7.7 (GNDPAD1), U7.8 (GNDPAD2), U8.2 (GND), U8.7 (GNDPAD1), U8.8 (GNDPAD2), U9.2 (GND), U9.7 (GNDPAD1), U9.8 (GNDPAD2), U10.2 (GND), U10.7 (GNDPAD1), U10.8 (GNDPAD2); also elsewhere on the board
unnamed: R14.2, R15.1, U4.3 (+)
unnamed: R17.1, U4.4, U5.2
unnamed: R18.1, U5.4, U9.1 (EN)
unnamed: R19.2, R20.1, U6.6 (ADJ)
unnamed: R21.2, R22.1, U7.6 (ADJ)
unnamed: R23.2, R24.1, U8.6 (ADJ)
unnamed: R25.2, R26.1, U9.6 (ADJ)
unnamed: R27.2, R28.1, U10.6 (ADJ)
VCC: C43.1, C44.1, C45.1, C46.1, C47.1, C48.1, C49.1, R14.1, R17.2, U4.5 (V+), U5.5 (VCC), U6.1 (EN), U6.3 (IN), U7.1 (EN), U7.3 (IN), U8.1 (EN), U8.3 (IN), U9.3 (IN), U10.1 (EN), U10.3 (IN); also elsewhere on the board

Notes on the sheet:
2.8v regulator supplies STM Vdd, image sensor i/os, and image sensor analog.
3.3v regulator supplies USB phy on STM this regulator must be powered up and down in the correct order
1.5v regulator supplies HM01B0 dvdd
1.2v regulator supplies HM0360 dvdd
1.8v regulator supplies ulpi voltage

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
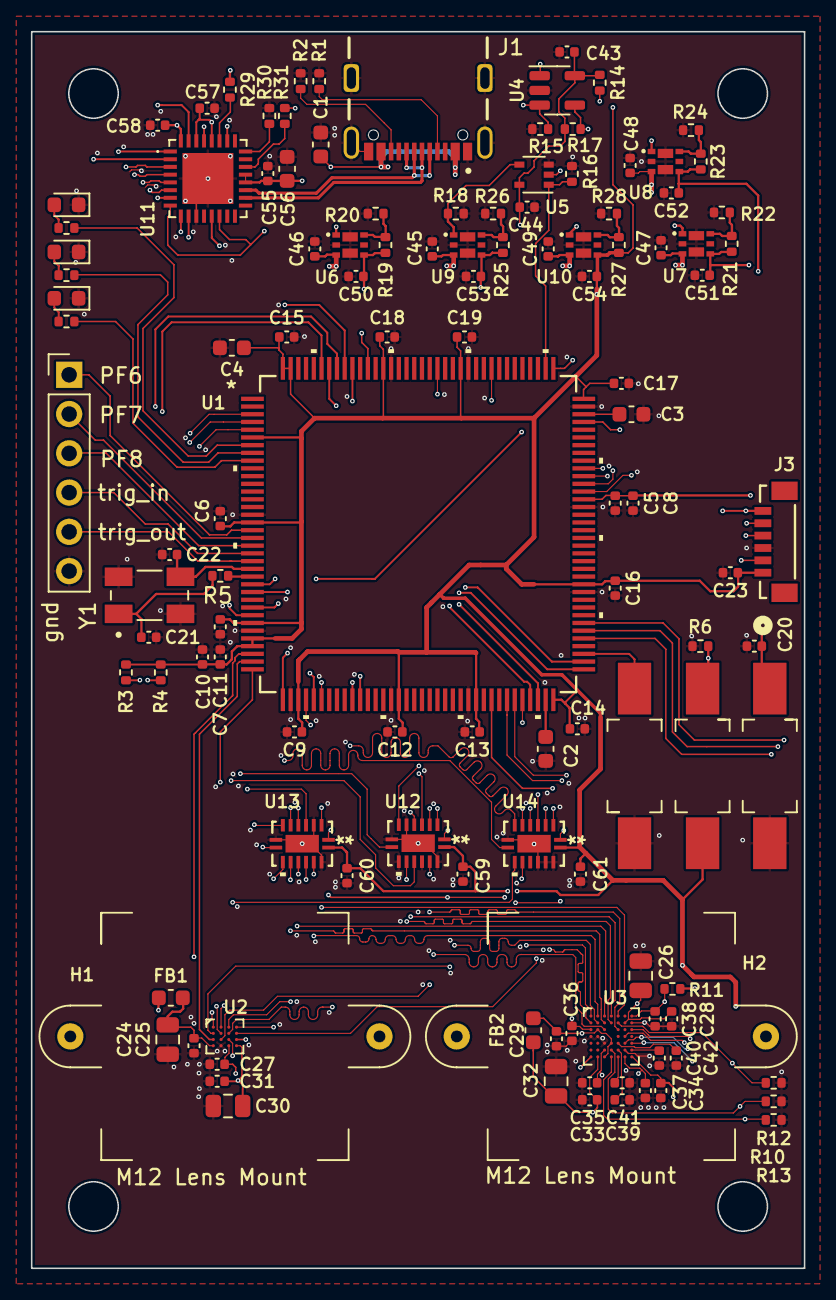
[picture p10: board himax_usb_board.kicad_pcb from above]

Board: 4 copper layers, 50.0 x 80.0 mm, 120 parts (0 on the bottom side), 106 nets.

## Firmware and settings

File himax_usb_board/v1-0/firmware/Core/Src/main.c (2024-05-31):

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
/* Includes ------------------------------------------------------------------*/
#include "main.h"
#include "cmsis_os.h"
#include "usb_device.h"

/* USER CODE BEGIN Includes */
#include "system_task.h"
#include "camera_read_task.h"
#include "camera_management_task.h"
#include "usb_task.h"
/* USER CODE END Includes */


DCMI_HandleTypeDef hdcmi;

I2C_HandleTypeDef hi2c1;

TIM_HandleTypeDef htim1;
TIM_HandleTypeDef htim2;
TIM_HandleTypeDef htim4;

osThreadId defaultTaskHandle;
uint32_t defaultTaskBuffer[ 128 ];
osStaticThreadDef_t defaultTaskControlBlock;
/* USER CODE BEGIN PV */

#define SYSTEM_TASK_BUFSZ 512
osThreadId systemTaskHandle;
uint32_t systemTaskBuffer[ SYSTEM_TASK_BUFSZ ];
osStaticThreadDef_t systemTaskControlBlock;

#define CAMERA_READ_TASK_BUFSZ 512
osThreadId cameraTaskHandle;
uint32_t cameraTaskBuffer[ CAMERA_READ_TASK_BUFSZ ];
osStaticThreadDef_t cameraTaskControlBlock;

#define CAMERA_MANAGEMENT_TASK_BUFSZ 512
osThreadId cameraManagementTaskHandle;
uint32_t cameraManagementTaskBuffer[ CAMERA_MANAGEMENT_TASK_BUFSZ ];
osStaticThreadDef_t cameraManagementTaskControlBlock;

#define USB_TASK_BUFSZ 512
osThreadId usbTaskHandle;
uint32_t usbTaskBuffer[ USB_TASK_BUFSZ ];
osStaticThreadDef_t usbTaskControlBlock;

#define USB_REQUEST_QUEUE_ITEM_SIZE (sizeof(usb_write_request_t))
#define USB_REQUEST_QUEUE_LENGTH 4
QueueHandle_t usb_request_queue = NULL;
StaticQueue_t usb_request_queue_static;
uint8_t usb_request_queue_storage_area[USB_REQUEST_QUEUE_ITEM_SIZE * USB_REQUEST_QUEUE_LENGTH];

#define USB_CDC_RX_QUEUE_ITEM_SIZE (sizeof(uint8_t))
#define USB_CDC_RX_QUEUE_LENGTH 1024
QueueHandle_t usb_cdc_rx_queue = NULL;
StaticQueue_t usb_cdc_rx_queue_static;
uint8_t usb_cdc_rx_queue_storage_area[USB_CDC_RX_QUEUE_ITEM_SIZE * USB_CDC_RX_QUEUE_LENGTH];

#define CAMERA_READ_TASK_CONFIG_QUEUE_ITEM_SIZE (sizeof(camera_read_config_t))
#define CAMERA_READ_TASK_CONFIG_QUEUE_LENGTH 8
QueueHandle_t camera_read_task_config_queue = NULL;
StaticQueue_t camera_read_task_config_queue_static;
uint8_t camera_read_task_config_queue_storage_area[
    CAMERA_READ_TASK_CONFIG_QUEUE_ITEM_SIZE * CAMERA_READ_TASK_CONFIG_QUEUE_LENGTH];

#define CAMERA_MANAGEMENT_TASK_REQUEST_QUEUE_ITEM_SIZE (sizeof(camera_management_request_t))
#define CAMERA_MANAGEMENT_TASK_REQUEST_QUEUE_LENGTH 32
QueueHandle_t camera_management_task_request_queue = NULL;
StaticQueue_t camera_management_task_request_queue_static;
uint8_t camera_management_task_request_queue_storage_area[
    CAMERA_MANAGEMENT_TASK_REQUEST_QUEUE_ITEM_SIZE * CAMERA_MANAGEMENT_TASK_REQUEST_QUEUE_LENGTH];

#define UART7_QUEUE_ITEM_SIZE sizeof(char)
#define UART7_QUEUE_LENGTH 512
QueueHandle_t uart7_queue = NULL;
StaticQueue_t uart7_queue_static;
uint8_t uart7_queue_storage_area[UART7_QUEUE_LENGTH];

/* USER CODE END PV */

void SystemClock_Config(void);
static void MX_GPIO_Init(void);
static void MX_DCMI_Init(void);
static void MX_I2C1_Init(void);
static void MX_TIM2_Init(void);
static void MX_TIM4_Init(void);
static void MX_TIM1_Init(void);
void StartDefaultTask(void const * argument);

/**
  * @brief  The application entry point.
  * @retval int
  */
int main(void)
{
  /* MCU Configuration--------------------------------------------------------*/

  /* Reset of all peripherals, Initializes the Flash interface and the Systick. */
  HAL_Init();

  /* Configure the system clock */
  SystemClock_Config();

  /* Initialize all configured peripherals */
  MX_GPIO_Init();
  MX_DCMI_Init();
  MX_I2C1_Init();
  MX_TIM2_Init();
  MX_TIM4_Init();
  MX_TIM1_Init();
  /* USER CODE BEGIN 2 */

  // enable 3v3 for ULPI transciever
  HAL_GPIO_WritePin(ldo_3v3_en_GPIO_Port, ldo_3v3_en_Pin, GPIO_PIN_SET);

  // Start ULPI refclk which is on TIM4 CH1, which is on APB1 and therefore has a frequency of
  // 96MHz.
  // REFSEL bits for ULPI refclk specify a 19.2MHz oscillator; we have a 192MHz sysclk, so we
  // can derive this from 96MHz. The USB3320C can tolerate a duty cycle of 20 - 80 % on its clock,
  // so it's ok to use TIM4 to divide 96MHz by 5, yielding a duty cycle of 40 or 60%.
  TIM4->CCER = 1;
  TIM4->CR1 |= (1 << 0);

  // should wait for a little bit after the timer is initialized to let the USB startup
  HAL_Delay(5);

  UART7_Init();

  /* USER CODE END 2 */

  /* USER CODE BEGIN RTOS_MUTEX */
  /* add mutexes, ... */
  /* USER CODE END RTOS_MUTEX */

  /* USER CODE BEGIN RTOS_SEMAPHORES */
  /* add semaphores, ... */
  /* USER CODE END RTOS_SEMAPHORES */

  /* USER CODE BEGIN RTOS_TIMERS */
  /* start timers, add new ones, ... */
  /* USER CODE END RTOS_TIMERS */

  /* USER CODE BEGIN RTOS_QUEUES */
  usb_request_queue = xQueueCreateStatic(USB_REQUEST_QUEUE_LENGTH,
                                         USB_REQUEST_QUEUE_ITEM_SIZE,
                                         usb_request_queue_storage_area,
                                         &usb_request_queue_static);

  usb_cdc_rx_queue = xQueueCreateStatic(USB_CDC_RX_QUEUE_LENGTH,
                                         USB_CDC_RX_QUEUE_ITEM_SIZE,
                                         usb_cdc_rx_queue_storage_area,
                                         &usb_cdc_rx_queue_static);

  camera_read_task_config_queue = xQueueCreateStatic(CAMERA_READ_TASK_CONFIG_QUEUE_LENGTH,
                                                     CAMERA_READ_TASK_CONFIG_QUEUE_ITEM_SIZE,
                                                     camera_read_task_config_queue_storage_area,
                                                     &camera_read_task_config_queue_static);

  camera_management_task_request_queue = xQueueCreateStatic(CAMERA_MANAGEMENT_TASK_REQUEST_QUEUE_LENGTH,
                                                     CAMERA_MANAGEMENT_TASK_REQUEST_QUEUE_ITEM_SIZE,
                                                     camera_management_task_request_queue_storage_area,
                                                     &camera_management_task_request_queue_static);

  uart7_queue = xQueueCreateStatic(UART7_QUEUE_LENGTH,
                                         UART7_QUEUE_ITEM_SIZE,
                                         uart7_queue_storage_area,
                                         &uart7_queue_static);

#if 0
  /* USER CODE END RTOS_QUEUES */

  /* Create the thread(s) */
  /* definition and creation of defaultTask */
  osThreadStaticDef(defaultTask, StartDefaultTask, osPriorityNormal, 0, 128, defaultTaskBuffer, &defaultTaskControlBlock);
  defaultTaskHandle = osThreadCreate(osThread(defaultTask), NULL);


  /* USER CODE BEGIN RTOS_THREADS */
#endif
#if 1
  osThreadStaticDef(systemTask,
                    system_task,
                    osPriorityNormal,
                    0,
                    SYSTEM_TASK_BUFSZ,
                    systemTaskBuffer,
                    &systemTaskControlBlock);
  systemTaskHandle = osThreadCreate(osThread(systemTask), NULL);
#endif
#if 1
  osThreadStaticDef(cameraTask,
                    camera_read_task,
                    osPriorityNormal,
                    0,
                    CAMERA_READ_TASK_BUFSZ,
                    cameraTaskBuffer,
                    &cameraTaskControlBlock);
  cameraTaskHandle = osThreadCreate(osThread(cameraTask), NULL);

  osThreadStaticDef(cameraManagementTask,
                    camera_management_task,
                    osPriorityNormal,
                    0,
                    CAMERA_MANAGEMENT_TASK_BUFSZ,
                    cameraManagementTaskBuffer,
                    &cameraManagementTaskControlBlock);
  cameraManagementTaskHandle = osThreadCreate(osThread(cameraManagementTask), NULL);
#endif

#if 1
  osThreadStaticDef(usbTask,
                    usb_task,
                    osPriorityNormal,
                    0,
                    USB_TASK_BUFSZ,
                    usbTaskBuffer,
                    &usbTaskControlBlock);
  usbTaskHandle = osThreadCreate(osThread(usbTask), NULL);
#endif

  /* USER CODE END RTOS_THREADS */

  /* Start scheduler */
  osKernelStart();
  /* We should never get here as control is now taken by the scheduler */
  /* Infinite loop */
  /* USER CODE BEGIN WHILE */
  while (1)
  {
    /* USER CODE END WHILE */

    /* USER CODE BEGIN 3 */
  }
  /* USER CODE END 3 */
}

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
/* USER CODE BEGIN 4 */
/**
 * put UART7_TX on PF7.
 */
void UART7_Init()
{
    __HAL_RCC_UART7_CLK_ENABLE();

    // init gpio
    GPIO_InitTypeDef GPIO_InitStruct = {0};
    GPIO_InitStruct.Pin = GPIO_PIN_7;
    GPIO_InitStruct.Mode = GPIO_MODE_AF_PP;
    GPIO_InitStruct.Pull = GPIO_NOPULL;
    GPIO_InitStruct.Speed = GPIO_SPEED_FREQ_LOW;
    GPIO_InitStruct.Alternate = GPIO_AF8_UART7;
    HAL_GPIO_Init(GPIOF, &GPIO_InitStruct);

    // init UART
    UART7->BRR = 416;
    UART7->CR1 |= (1 << 3) | (1 << 0);

    // init NVIC for uart
    HAL_NVIC_SetPriority(UART7_IRQn, 10, 0);
    HAL_NVIC_EnableIRQ(UART7_IRQn);
}


void putch(char ch)
{
    // put character on queue
    xQueueSendToBack(uart7_queue, &ch, 0);

    // TXEIE
    UART7->CR1 |= (1 << 7);
}

void putch_from_isr(char ch)
{
    // put character on queue
    xQueueSendToBackFromISR(uart7_queue, &ch, NULL);

    // TXEIE
    UART7->CR1 |= (1 << 7);
}

/* USER CODE END 4 */

/**
  * @brief  Period elapsed callback in non blocking mode
  * @note   This function is called  when TIM3 interrupt took place, inside
  * HAL_TIM_IRQHandler(). It makes a direct call to HAL_IncTick() to increment
  * a global variable "uwTick" used as application time base.
  * @param  htim : TIM handle
  * @retval None
  */
void HAL_TIM_PeriodElapsedCallback(TIM_HandleTypeDef *htim)
{
  if (htim->Instance == TIM3) {
    HAL_IncTick();
  }
}

/**
  * @brief  This function is executed in case of error occurrence.
  * @retval None
  */
void Error_Handler(void)
{
  /* USER CODE BEGIN Error_Handler_Debug */
  /* User can add his own implementation to report the HAL error return state */
  __disable_irq();
  while (1)
  {
  }
  /* USER CODE END Error_Handler_Debug */
}

#ifdef  USE_FULL_ASSERT
/**
  * @brief  Reports the name of the source file and the source line number
  *         where the assert_param error has occurred.
  * @param  file: pointer to the source file name
  * @param  line: assert_param error line source number
  * @retval None
  */
void assert_failed(uint8_t *file, uint32_t line)
{
  /* USER CODE BEGIN 6 */
  /* User can add his own implementation to report the file name and line number,
     ex: printf("Wrong parameters value: file %s on line %d\r\n", file, line) */
  /* USER CODE END 6 */
}
#endif /* USE_FULL_ASSERT */

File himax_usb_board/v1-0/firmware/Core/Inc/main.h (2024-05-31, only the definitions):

#define led0_Pin GPIO_PIN_13
#define led0_GPIO_Port GPIOC
#define led1_Pin GPIO_PIN_14
#define led1_GPIO_Port GPIOC
#define led2_Pin GPIO_PIN_15
#define led2_GPIO_Port GPIOC
#define gpio0_Pin GPIO_PIN_6
#define gpio0_GPIO_Port GPIOF
#define gpio1_Pin GPIO_PIN_7
#define gpio1_GPIO_Port GPIOF
#define gpio2_Pin GPIO_PIN_8
#define gpio2_GPIO_Port GPIOF
#define gpio3_Pin GPIO_PIN_9
#define gpio3_GPIO_Port GPIOF
#define gpio4_Pin GPIO_PIN_10
#define gpio4_GPIO_Port GPIOF
#define hm01b0_int_Pin GPIO_PIN_0
#define hm01b0_int_GPIO_Port GPIOA
#define hm01b0_trig_Pin GPIO_PIN_1
#define hm01b0_trig_GPIO_Port GPIOA
#define hm01b0_mclk_Pin GPIO_PIN_2
#define hm01b0_mclk_GPIO_Port GPIOA
#define hm0360_mclk_Pin GPIO_PIN_11
#define hm0360_mclk_GPIO_Port GPIOE
#define hm0360_trig_Pin GPIO_PIN_13
#define hm0360_trig_GPIO_Port GPIOE
#define hm0360_int_Pin GPIO_PIN_14
#define hm0360_int_GPIO_Port GPIOE
#define camera_select_Pin GPIO_PIN_15
#define camera_select_GPIO_Port GPIOE
#define user_button_Pin GPIO_PIN_14
#define user_button_GPIO_Port GPIOB
#define hm0360_clksel_Pin GPIO_PIN_8
#define hm0360_clksel_GPIO_Port GPIOD
#define hm0360_xshut_Pin GPIO_PIN_9
#define hm0360_xshut_GPIO_Port GPIOD
#define hm0360_xsleep_Pin GPIO_PIN_10
#define hm0360_xsleep_GPIO_Port GPIOD
#define ldo_3v3_en_Pin GPIO_PIN_15
#define ldo_3v3_en_GPIO_Port GPIOA
#define ulpi_refclk_Pin GPIO_PIN_6
#define ulpi_refclk_GPIO_Port GPIOB

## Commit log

2023-11-01 schematic wip
    [bus_mux.kicad_sch, himax_usb_board.kicad_sch, image_sensors.kicad_sch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]
2023-11-10 board routing wip
    [bus_mux.kicad_sch, himax_usb_board.kicad_pcb, himax_usb_board.kicad_sch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]
2024-01-09 hardware wip
    [ABM3B-12.000MHZ-B2-T.step, bus_mux.kicad_sch, himax_usb_board.kicad_pcb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]
2024-01-09 change dir structure
    [ABM3B-12.000MHZ-B2-T.step, bus_mux.kicad_sch, himax_usb_board.kicad_pcb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]
2024-01-09 rename some files
    [ABM3B-12.000MHZ-B2-T.step, bus_mux.kicad_sch, himax_usb_board.kicad_pcb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]
2024-01-12 update some hardware design files
    [ABM3B-12.000MHZ-B2-T.step]
2024-01-12 firmware connects over USB and appears to read camera frames
2024-01-22 rename some stuff
    [ABM3B-12.000MHZ-B2-T.step, bus_mux.kicad_sch, himax_usb_board.kicad_pcb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]
2024-01-25 fix startup bug; was due to gated pixclk on image sensor
    [camera_task.c, main.c]
2024-01-30 camera wip; add exti9 interrupt for trigger in
2024-03-12 camera updates at runtime wip
2024-03-12 runtime camera updates pass smoke test
2024-03-12 fix race condition in camera_read_task; runtime camera config update appears to work.
    [camera_read_task.c]
2024-04-22 update serialcam to use new camera command interface; serialcam.py must enable DCMI to start video.
2024-05-03 camera python script update WIP
2024-05-03 fix numpy dimensioning error in camera interface
    [camerainterface.py]
2024-05-16 fix DMA reset bug
    [camera_management_task.c, camera_read_task.c, camerainterface.py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]
2024-05-24 uart7 now outputs cprintf on PF7
2024-05-31 fix frame alignment bug
    [camera_read_task.c, main.c, main.h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]

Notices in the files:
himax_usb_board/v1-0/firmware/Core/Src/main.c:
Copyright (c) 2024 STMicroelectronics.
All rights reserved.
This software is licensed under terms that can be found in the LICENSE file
